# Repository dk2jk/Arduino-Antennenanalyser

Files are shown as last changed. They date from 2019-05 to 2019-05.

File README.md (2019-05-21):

<b>Arduino Antennenanalyser</b>

Dieser Antennenanalyser basiert auf Ver&ouml;ffendlichungen von K6BEZ und DG7EAO.

Der Antennenanalyser besteht aus einer Ohmschen SWR Messbr&uuml;cke('Resistive SWR Bridge'), die von einem DDS- Generator gespeist wird.

Die Einstellung der Frequenz und die Messung der Br&uuml;ckenspannung erfolgt &uuml;ber einen Arduino - Mikrocontroller.
Ein PC dient zur Anzeige und Bedienung.

<a href="https://github.com/dk2jk/arduino_antennenanalyser/tree/master/documents">->Beschreibung</a>

Bedienprogramm VNA.exe:
siehe: Abschnitt:&nbsp; "VNA PC Software"  in: <a href="http://www.dg7eao.de/arduino/antennen-analysator/">http://www.dg7eao.de/arduino/antennen-analysator/</a>

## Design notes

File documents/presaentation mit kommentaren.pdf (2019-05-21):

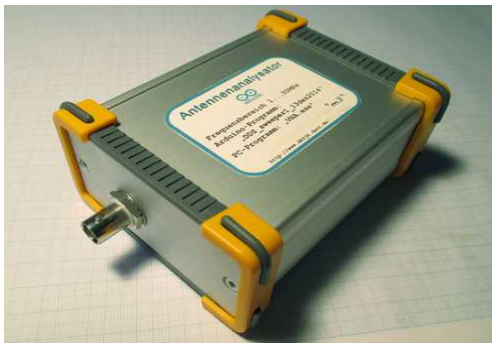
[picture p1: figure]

dk2jk | 1/13
DK2JK | 1/13

„Antennenanalyser“ mit ARDUINO

Titel

### „Antennenanalyser“ mit ARDUINO

Ein Selbstbauprojekt

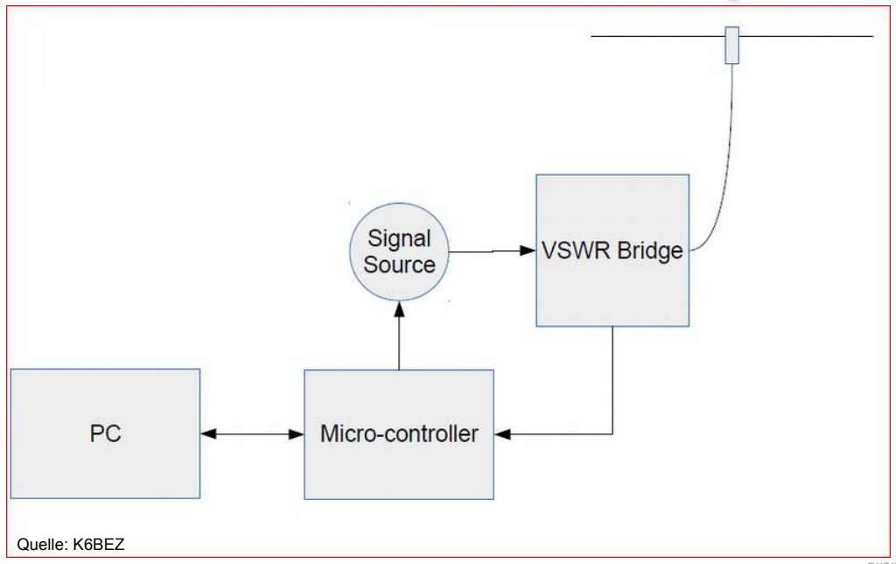
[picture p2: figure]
Quelle: K6BEZ

DK2JK 2/13

„Antennenanalyser“ mit ARDUINO

Block Diagramm

Das Blockdiagramm zeigt eine SWR-Messbrücke, die von einer Signalquelle gespeist wird. Ein Mikrocontroller steuert die Signalquelle und holt die Messwerte von der SWR-Messbrücke. Die Messwerte werden vom PC graphisch angezeigt

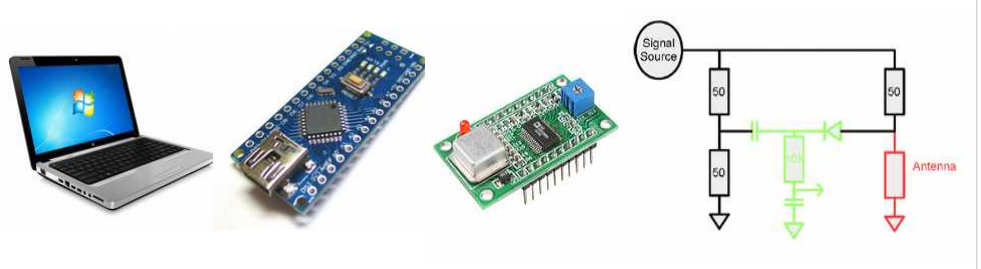
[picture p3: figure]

DK2JK 3/13

„Antennenanalyser“ mit ARDUINO

Komponenten

Windows PC | Arduino 'Nano' | DDS | Messbrücke
- CPU-Chip : Atmel Atmega328 16 MHz
- Modul fertig aufgebaut in SMD
- Bootlader via USB
- Entwicklungsoberfläche ( IDE) frei verfügbar
- Programmiersprache C / C++
- Preiswert ca. 4 Euro ( China )

●
- DDS-Chip : Analog Devices AD9850
- Modul fertig aufgebaut in SMD
- Schnittstelle : SPI ( Clock + Daten+ Update )
- Preiswert ca. 10Euro ( China)

●
- Messbrücke vgl. QRP-Report 1-2015

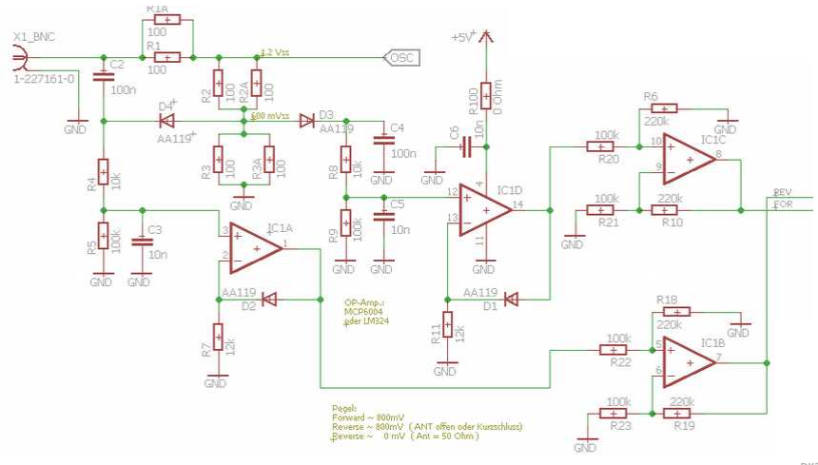
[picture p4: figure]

DK2JK 4/13

„Antennenanalyser“ mit ARDUINO

Schaltung Analogteil

Messbrücke : R1,R2,R3

V (forward) zwischen R2 und R3
V( reflected) zwischen R1 und BNC-Buchse
OP's hinter D3 / D4 sind log. Verstärker zum Kompensieren der Ge-Diodenkennlinie.
Der zweite OP hat die Verstärkung 2, so dass etwa max. 700mV am ADC anliegen. Der ADC misst von 0 bis 1,1 Volt ( Ref.Spannung).
Als OP muss ein Typ genommen werden, der bis Null Volt ohne neg. Betriebsspannung funktioniert ( LM324, 2x LM358) . Ein echter Rail-To-Rail-OP ist nicht erforderlich ( z.B. MCP 6004 ).

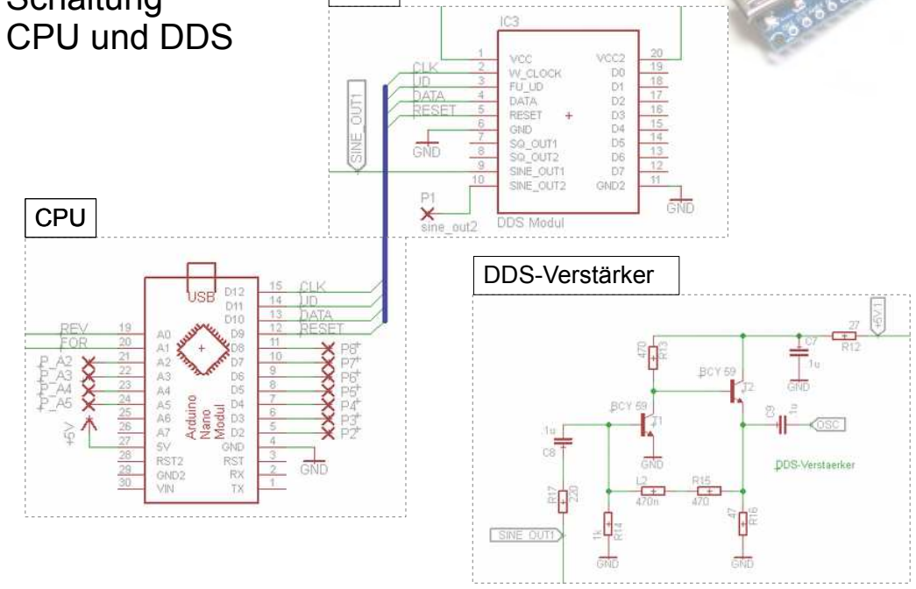
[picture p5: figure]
CPU und DDS; CPU; DDS-Verstärker

DK2JK 5/13

„Antennenanalyser“ mit ARDUINO

Schaltung

DDS

Zentrales Glied ist der DDS. Dieser ist einstellbar von 1 Hz bis 30 Mhz. Je höher die Frequenz ist, desto 'treppenförmiger' sieht die Ausgangsspannung aus ( Oszillator = 125 MhHz ).
Die Programmierung des DDS erfolgt sehr einfach über eine serielle Schnittstelle mit den Signalen Clock, Date und Chipselect ( SPI).
Der DDS liefert ca. 400mV ss, was für die Messbrücke etwas wenig ist. Deshalb wird hier ein Verstärker nachgeschaltet, der das Signal auf 1,4 Vss anhebt. Andere Schaltungsbeispiele verwenden hier einen MMIC, dem jedoch ein Dämpfungsglied vorgeschaltet werden muss.

DK2JK 6/13

„Antennenanalyser“ mit ARDUINO

Layout

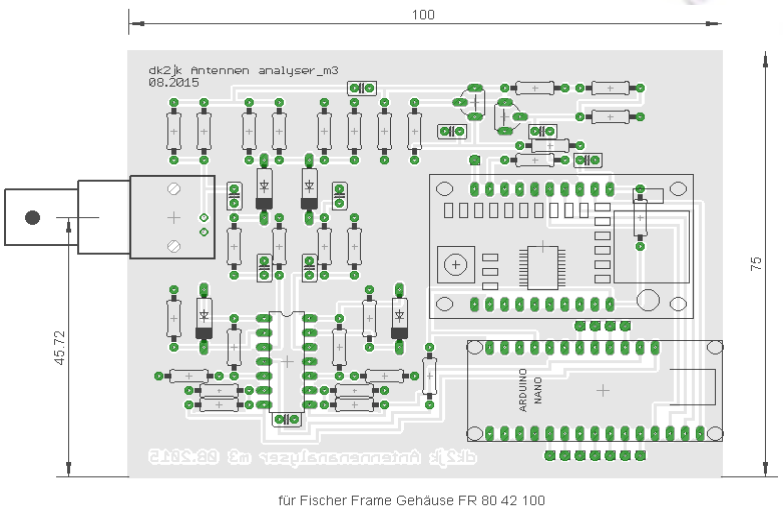
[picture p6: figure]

Hier ein Layout 100 mm x 75 mm

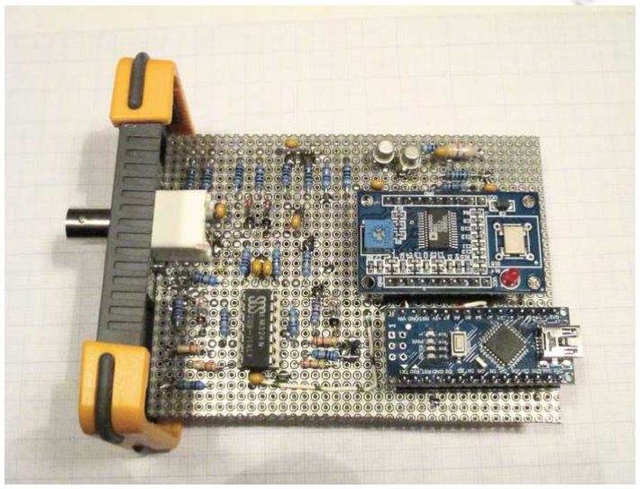
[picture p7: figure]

DK2JK 7/13

„Antennenanalyser“ mit ARDUINO

Prototyp

Die Platine wurde in ein Fischer 'Frame Gehäuse' eingebaut; ebenso würde ein Profilgehäuse TUF 80 42 100 ME gehen ( ohne die
Kunststoffrahmen ) .
Die einzig notwendigen mechanischen Arbeiten sind ist das Sägen des Lochs für die BNC-Buchse und die USB-Buchse.
Die Platine passt in eine der vorhandenen Führungen im Gehäuse.

Der Arduino sitzt knapp am Rand, damit auch USB-Stecker mit etwas dickerem Stecker passen.
Zwischen Front und BNC-Buchse müssen noch 2mm untergelegt werden, da durch die Gummidichtungen die Front nicht direkt am Rahmen liegt. (Die Platine wurde für 100mm Gehäusetiefe entworfen ).
( Masseverbindung zwischen Platine und Gehäuse ist zu prüfen)

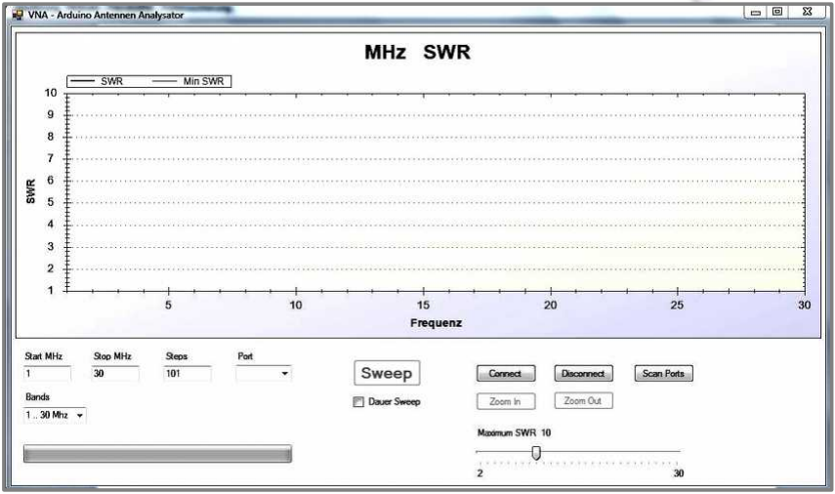
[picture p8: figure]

DK2JK 8/13

„Antennenanalyser“ mit ARDUINO
PC-Programm „VNA.exe“

Quelle: DG7EAO

Hier die Bedienoberfläche von Norbert DG7EA0 ( in Visual Basic geschrieben).
Gestartet wird mit 'Scan Ports'. Im Listenfeld 'Ports' wählt man den benutzten Port aus; evtl. im Gerätemanager nachschauen. Mit 'Connect' und 'Sweep' startet der Scanvorgang.
Der Frequenzbereich ( Start, Stop ) kann geändert werden, ebenso die Auflösung ( 'Steps' ).

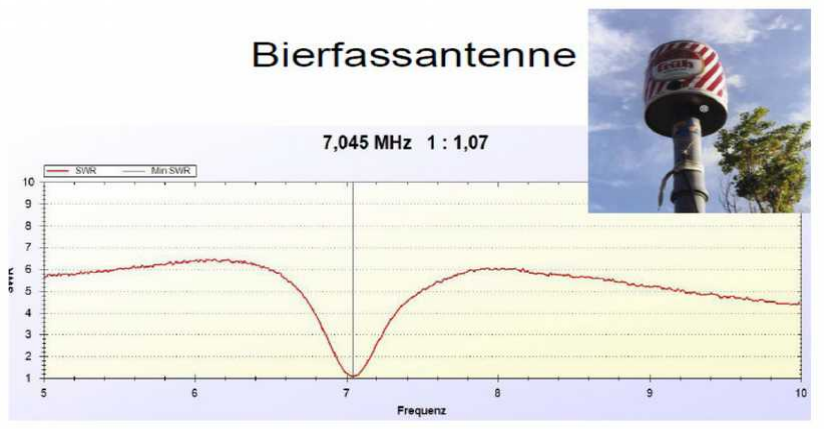
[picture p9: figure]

DK2JK 9/13

„Antennenanalyser“ mit ARDUINO

Messung(1)

Hier als Beispiel die Messung einer Bierfassantenne.

Was kann man noch alles damit anstellen ?

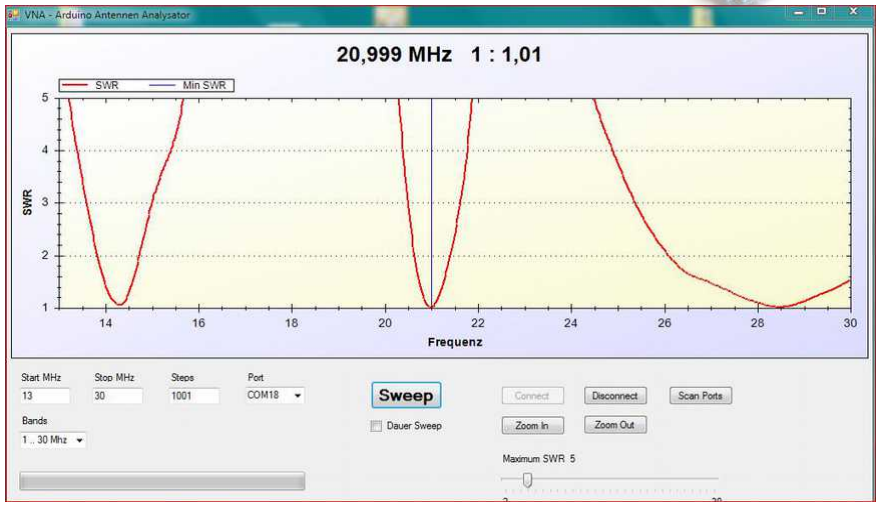
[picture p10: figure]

DK2JK 10/13

„Antennenanalyser“ mit ARDUINO

Messung(2)

Fritzel GPA

Hier als Beispiel die Messung einer 3 Band Fritzel GPA

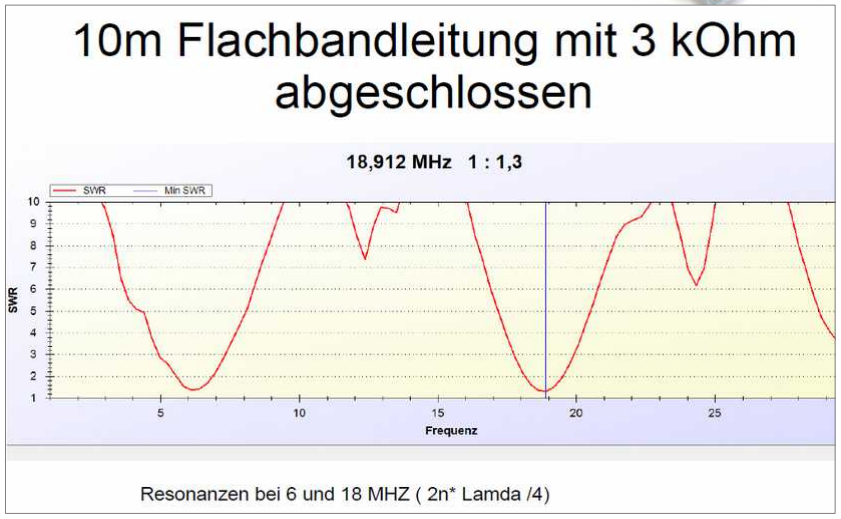
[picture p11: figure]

DK2JK 11/13

„Antennenanalyser“ mit ARDUINO

Messung(3)

Hier als Beispiel die Messung einer Flachbandleitung ( alte Fernsehleitung ).

Verkürzungsfaktor 6/7 ~ 0,85
Zur Erinnerung : Lambda/ 4 transformiert Hochohmig in Niederohmig.

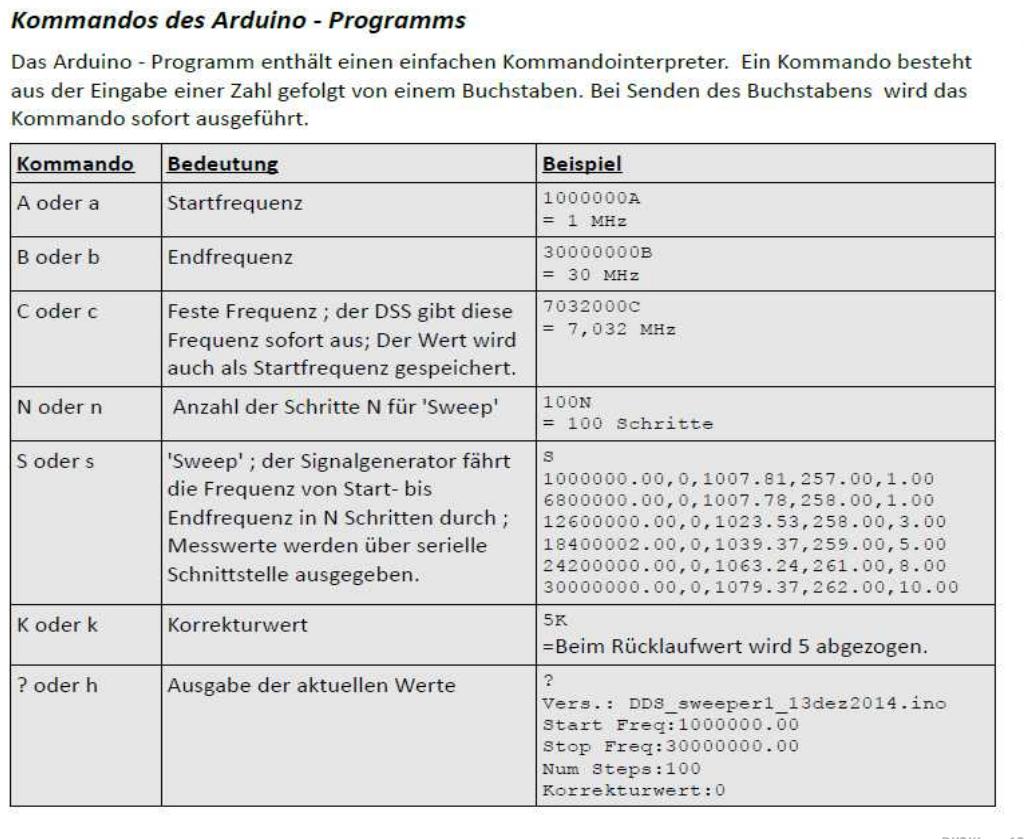
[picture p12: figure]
„Antennenanalyser“ mit ARDUINO

DK2JK 12/13

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
Die Bedienung des Arduino erfolgt über einfache Kommandos.
Mit dem Kommnado 's' wird die Messreihe in Form einer Tabelle ausgegeben, die mit dem PC-Programm VNA.exe graphisch angezeigt wird. Es würde auch mit EXCEL gehen.

DK2JK 13/13

„Antennenanalyser“ mit ARDUINO

Quellen

K6BEZ:
http://www.hamstack.com/hs_projects/antenna_analyzer_docs.pdf

DG7EAO :
http://lima05web.wordpress.com/2014/03/22/arduino-antennen-analysator-dg7eao/

DK2JK:
http://dk2jk.darc.de/arduino/antennenanalyser/

DDS:
http://www.analog.com/static/imported-files/data_sheets/AD9850.pdf

Arduino:
http://www.arduino.cc/

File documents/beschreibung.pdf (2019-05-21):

# Antennenanalyser mit Arduino

# Beschreibung

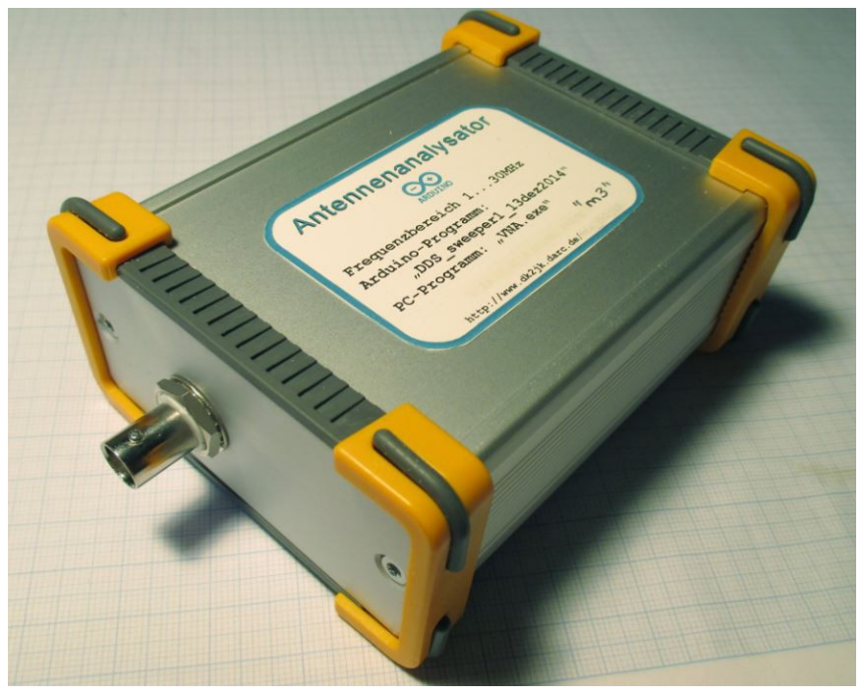
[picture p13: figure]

Seite 1 von 11 Seiten (03.2016 dk2jk)

### 1. Allgemein

Der Antennenanalyser besteht aus einer Ohmschen SWR Messbrücke( 'Resistive SWR Bridge'), die von einem DDS- Generator gespeist wird. Die Einstellung der Frequenz und die Messung der Brückenspannung erfolgt über einen Arduino -Mikrocontroller. Ein PC dient zur Anzeige und Bedienung.

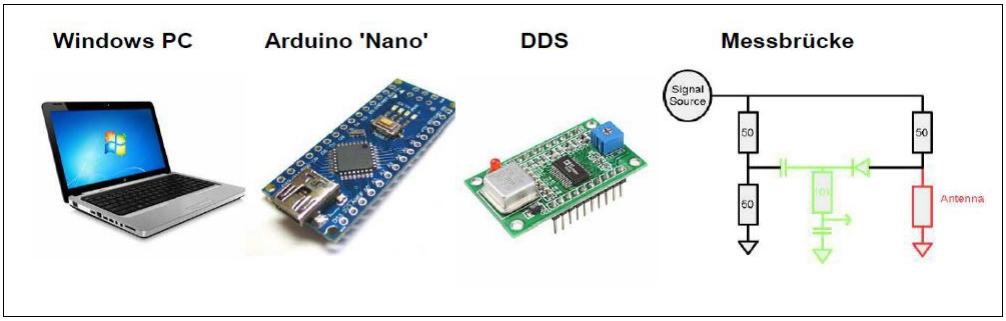
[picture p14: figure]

### 2. Anwendungen

- SWR- Messung 1 bis 30 Mhz
- Signalgenerator bis 30Mhz
- Resonanzmessung
- Telegraphie - Bakensender

### 3. Schaltungsbeschreibung

Die Frequenz des DDS AD9850 wird über 4 Steuerleitungen vom Mikrocontroller eingestellt. Die Frequenz kann auf 1 Hz genau programmiert werden. Das Ausgangssignal ist nahezu sinusförmig. Der DDS liefert einen Pegel von ca. 400mVss. Dieses Signal wird durch den DDS- Verstärker mit den Transistoren Q1 & Q2 verstärkt und auf ca. 1Vss an 50 Ohm angehoben.
Die Messung der Brückenspannung erfolgt über zwei Messkanäle. Jeder Messkanal besteht aus einer Spitzenwertgleichrichtung mit nachfolgendem logarithmischen Verstärker, welcher mit der gleichen Dioden bestückt ist wie der Gleichrichter; so wird die nichtlineare Kennlinie des Spitzenwertgleichrichters kompensiert. Es werden Germaniumdioden ( AA1xx, OAxx, 1N34, 1N60P ) verwendet, da Siliziumdioden bei dem geringen Pegel noch keine ordentliche Spannung liefern. Im Prototyp werden 1N60P verwendet. Der zweite OP verstärkt das Signal auf ca. 500mV am Eingang des Analog-Digital-Wandlers des Mikrocontrollers. Um bei den kleinen Spannungen im mV - Bereich die Offsetfehler klein zu halten, sind die OPs möglichst symmetrisch beschaltet. Als OP genügt ein LM324, der bei + 5Volt und 0-Volt- Versorgung Ausgangsspannungen von 0 Volt bis ca. 3 Volt Ausgangsspannung liefert.

Seite 2 von 11 Seiten (03.2016 dk2jk)

Abb. 1: Komponenten [Ref.1]

### 4. Aufbau

Alle Bauelemente befinden sich auf einer Platine 100mm x 75mm, die in die Führungsschienen eines Profilgehäuses passt ( Fischer Frame Gehäuse FR 80 42 100 ME [Ref.6] ). Das DDS- und Arduino - Nano- Modul sind in IC- Sockel mit doppeltem Federkontakt gesteckt. Für die Bestückung von Hand hat die Platine extra große Pads mit Durchkontaktierungen. Die Platine wird durch die BNC-Buchse an der Front festgehalten.

### 5. Bestückung

- Arduino- Board vorbereiten: Das Arduino- Modul hat je nach Lieferung evtl. noch keine Stiftleisten; Dazu werden ein passender IC- Sockel, die mitgelieferten 15-poligen Stifte und die Nano-Board-Platine zusammengesteckt und die Stifte oben an 4 Ecken verlötet. Die Stifte werden senkrecht ausgerichtet und endgültig verlötet. Die 6-pol. Stiftleiste auf dem Nano-Board ( ISP-Stecker) braucht nicht bestückt werden.
- IC-Sockel für Nano-Board vorbereiten: Aus einem 40-
poligen IC-Sockel wird ein 2 x 15-poliger
geschnitten; bei älteren Platinen gibt es an der 'Nord-Ost-Seite' für 3 Pins des Nano-Boards keine Pads, daher müssen die zugehörigen Stifte des Sockels flachgelegt werden. Zunächst IC-Sockel an 4 äußeren Pins fixieren und dann endgültig anlöten.
- IC-Sockel für das DDS-Board vorbereiten: Ein 20-poliger IC-Sockel wird in der Mitte zu 2 x 10 Pins längs geteilt. Nun das DDS-Board auf die Kontaktreihen stecken und auf der Platine platzieren. Den IC-Sockel an 4 äußeren Pins fixieren und dann endgültig anlöten.
- Entfernen des DDS - Moduls und des Nano-Boards.
- Bestückung der restlichen Bauelemente, wobei mit den
niedrigsten begonnen wird. Falls die Bauelemente nicht
sortiert sind, erst messen und sofort an passender Stelle einlöten. Bei den Dioden Polarität beachten!
- Einlöten der BNC - Buchse; hierbei darauf achten, dass diese rechtwinklig auf der Platine sitzt.
- Zuletzt den OP in den 14-poligen IC_Sockel stecken.
- DDS - Modul und Nano-Board wieder stecken.

### 6. Verbindung Aufnehmen

Was wird benötigt?
- USB-Kabel mit USB Mini-Stecker.
- | Arduino Programm | 'dds_sweeper_xx.ino' | [Ref.3]
- Programm 'VNA.EXE' mit zugehörigen DLLs [Ref.2]
- Microsoft Runtime Library DotNet 4.x
- Arduino IDE z.B. Arduino 1.6.x [Ref.5]

Die Module „DDS“ und „Arduino Nano“ sind
gesteckt. Nun wird der USB-Port mit dem Rechner verbunden. Jetzt sollte am Nano-Board die grüne und am DDS- Board die rote Power-LED leuchten. Falls der PC das Board nicht erkennt, so ist die Installation eines Treibers erforderlich [Ref. 3].
Nun wird die Arduino - IDE aufgerufen. Als erstes wird das Board 'Nano' ausgewählt und der COM -Port eingestellt.

Seite 3 von 11 Seiten (03.2016 dk2jk)

Abb. 2: Arduino-Nano-Sockel

Abb. 3: DDS-Sockel

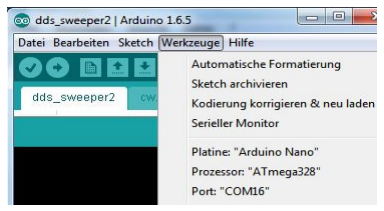
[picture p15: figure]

Abb. 4 COM-Port

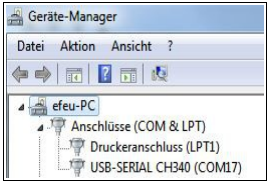
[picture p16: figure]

Zum Überprüfen, welcher COM- Port vom Arduino belegt wird, kann man im Gerätemanager nachsehen („devmgmt.msc“); dort nach „USB -Serial CH340“ suchen.

### 7. Erster Test

Arduino mit Programm 'dds_sweeper2.ino' [Ref.3] laden. Mit dem Knopf 'Hochladen' ( Pfeil nach rechts ) oder 'Strg+U' wird ein Programm in den Arduino -Mikrocontroller geladen. Nach dem Hochladen rufen wir den seriellen Monitor des Arduino auf über 'Werkzeuge' -> 'serieller Monitor'. Die Baudrate muss auf 57600 stehen! Nun geben wir in der Eingabezeile des Monitors ein
'7032000c' ( d.h. 7,032 Mhz als Dauersignal )
Das Programm sendet nun ein Dauersignal auf 7,032 Mhz. Auf dieser Frequenz 7,032 Mhz sollte jetzt ein Träger hörbar sein. Evtl. die Frequenz nach eigenen Bedürfnissen einstellen.

### 8. Offset prüfen

Zum Prüfen des Offsets geben wir die Frequenz Null ein
'0a0b10n' ( d.h. Von 0 Mhz bis 0 Mhz in 10 Schritten )
Mit
's'
wird der Durchlauf ( Sweep ) gestartet. Die Anzeigewerte für Vorlauf und Rücklauf in der 4. und 5. Spalte sollten nahe Null sein ( < 40 ). Ohne Eingangssignal wird nur der Offset gemessen;

### 9. Funktionstest 'dds-sweeper'

Wir nehmen eine KW-Empfänger und stellen ihn auf eine Frequenz ein ( Beispiel: 7,032 Mhz ). Als Betriebsart wählen wir CW oder SSB. Jetzt tippen wir am Terminal ( „Arduino – Serial - Monitor“ ) ein:
'7032000c' | ( d.h. 7,032 Mhz als Dauersignal )
'?' | | ( d.h. Statusanzeige )
Die Eingabe erfolgt in „Hertz“ . Das Kommando 'c' stellt diese Frequenz ein und das Kommando '?' zeigt die aktuellen Einstellungen auf dem Bildschirm an. Im KW-Empfänger sollte jetzt ein Signalton hörbar sein; vielleicht kann man einen kurzen Draht als Antenne in die Koaxbuchse als „Sendeantenne“ stecken. Wir können auch den Bereich, der durchlaufen wird, ausprobieren: ( Die Eingaben werden immer mit der Enter - Taste abgeschlossen ). Wir tippen ein:
'7000000a' | Startfrequenz = 7.000 MHz
'7001000b' | Endfrequenz = 7.001 MHz
| '?' | Status Anzeige
Jetzt | 's' | eingeben: Das Terminal zeigt die durchlaufenen Frequenzen an.

Im KW-Empfänger müsste jetzt ein ansteigender oder abfallender Ton hörbar sein – je nach eingestelltem Seitenband.

Noch ein Experiment: Wir ändern die Schrittanzahl ( 'Num Steps' ) auf 10, indem wir eingeben:
'10n' | ( d.h. 10 Schritte )
Wenn wir jetzt wieder 's' eingeben, sollte man im KW-Empfänger deutlich die Frequenzschritte hören können. Wir haben bis jetzt nachwiesen, dass der DDS Signale erzeugt.

Seite 4 von 11 Seiten (03.2016 dk2jk)

Abb. 5: Gerätemanager

Jetzt schließen wir wieder den 50-Ohm-Widerstand an. Eine Ausgabe von Daten erfolgt mit dem Kommando 's' am Terminal ( „Arduino – Serial -Monitor“ ) :
Die 3. Spalte gibt den SWR - Wert mal 1000 wieder; es sollten also bei einem 50-Ohm
Abschlusswiderstand Werte etwas größer als 1000 entsprechend einem SWR von 1.0 angezeigt werden.

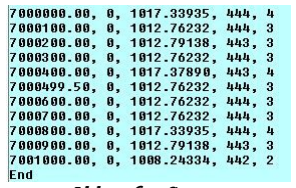
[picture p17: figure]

Die Tests jetzt mit den anderen Widerständen wiederholen:
100 Ohm | SWR= 2,0 | 25 Ohm | SWR= 2,0
75 Ohm | SWR= 1,5 | 33,3 Ohm | SWR= 1,5
150 Ohm | SWR= 3,0
Die Werte sollten ungefähr eingehalten werden. An dieser Stelle muss betont werden, dass dieser 'Antennenanalyser' kein Präzisionsinstrument ist.

### 10. Bedienoberfläche VNA.exe

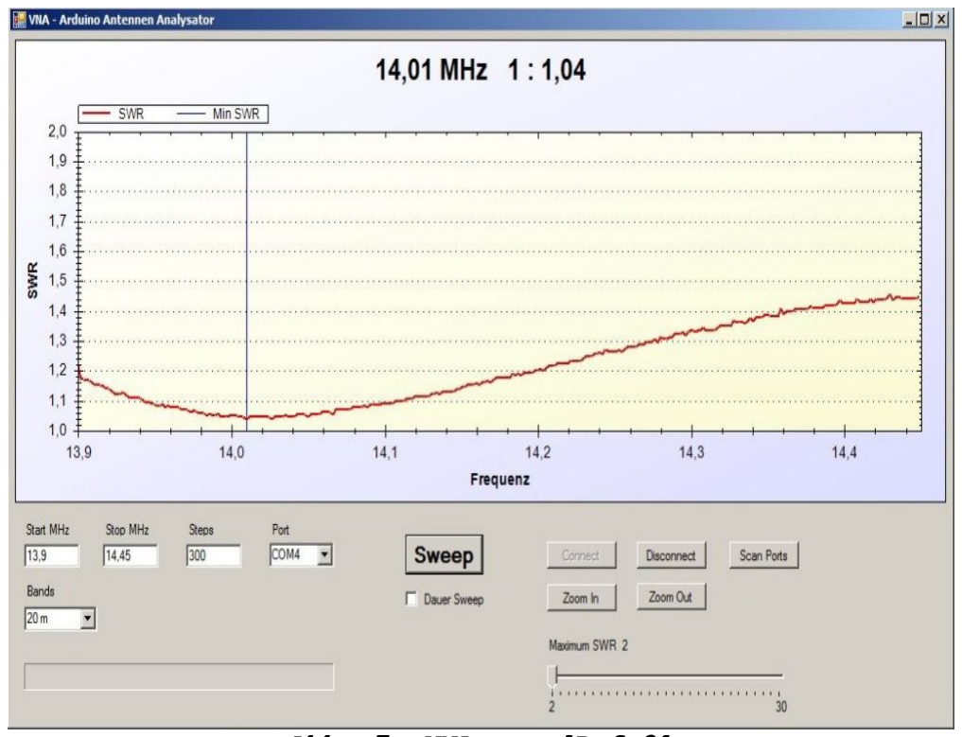
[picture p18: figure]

Die Software ist unter DotNet programmiert und benötigt eine aktuelle Version des DotNet Frameworks (Version 4.0 oder höher). Dieses kann kostenlos von Microsoft herunter geladen werden. Ein Software Installation ist nicht erforderlich. Es reicht, das Verzeichnis mit den Programmdateien an eine beliebige Stelle zu kopieren und die Datei VNA.exe zu starten. Nach dem Programmstart wählt man unter Port die Com - Schnittstelle des USB – Adapters aus. Mit einem Klick auf Connect wird eine serielle Verbindung zum Arduino Modul hergestellt. Unter Start MHz und Stop MHz ist der Frequenzbereich 1 .. 30 MHz voreingestellt. Diesen kann man beliebig ändern oder mit der Auswahlbox Bands ein Amateurfunkband wählen. Durch einen Klick auf Sweep werden die Daten an das Arduino Modul gesendet, dieses antwortet mit den entsprechenden SWR - Werten. Aus diesen wird dann eine Verlaufskurve gezeichnet. Unter Steps ist als Wert 101 eingestellt. Dies bedeutet, dass bei einem Frequenz - Sweep 101 Frequenzen gemessen werden. Man kann diesen Wert bis auf 1000 erhöhen, dann bekommt man eine höhere Auflösung mit bis zu 1000 Messpunkten – die Messung dauert dann aber etwas länger. Die Auflösung erhöht sich auch, wenn man den Frequenzbereich verkleinert, z.B. statt 1 .. 30 MHz >> 13 .. 15 MHz. Dies erreicht man auch

Seite 5 von 11 Seiten (03.2016 dk2jk)

Abb. 6: Sweep

Abb. 7: VNA.exe [Ref.2]

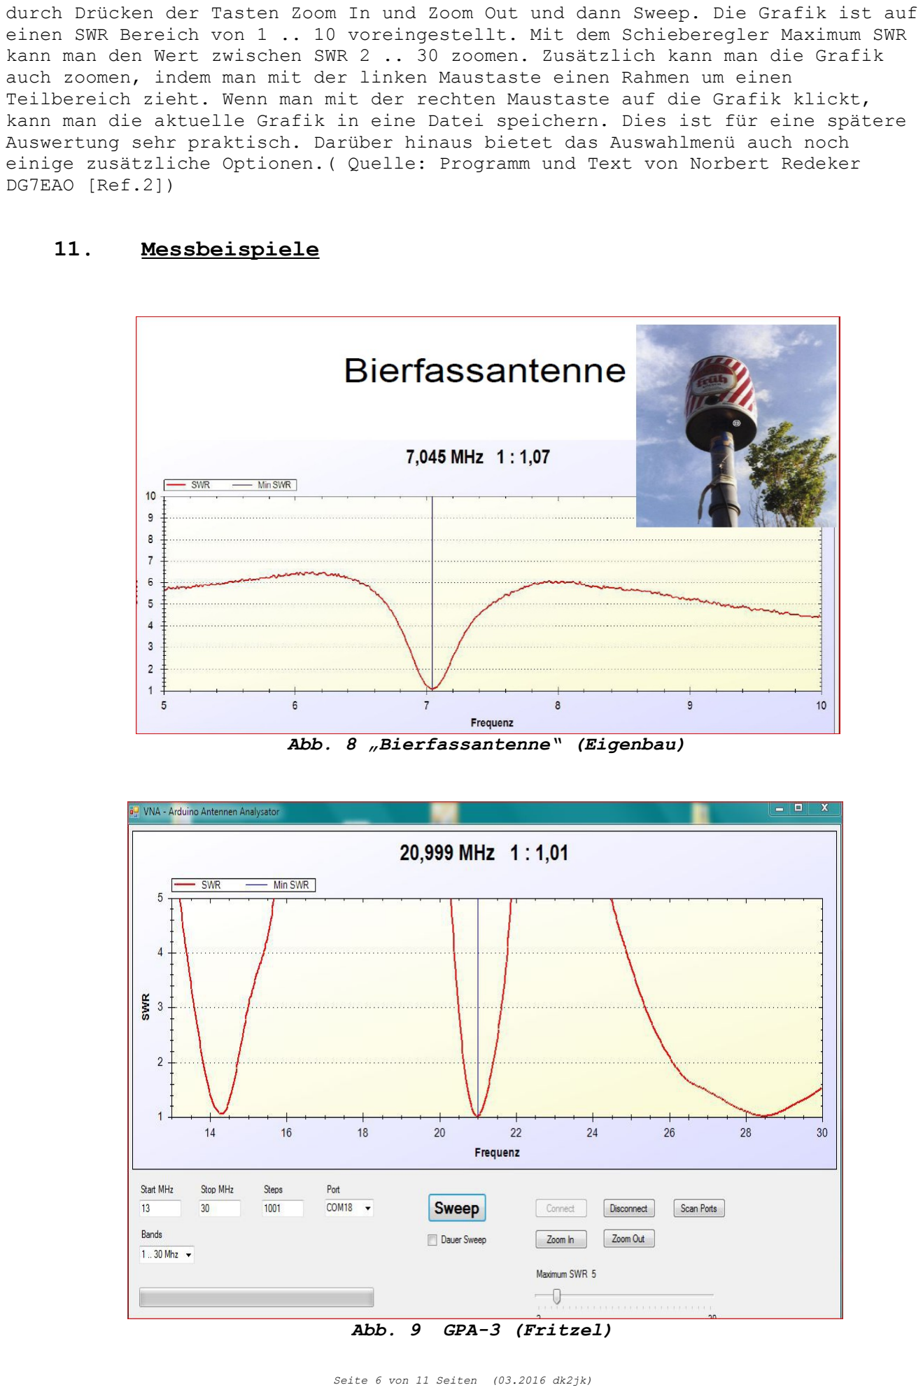
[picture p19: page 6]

durch Drücken der Tasten Zoom In und Zoom Out und dann Sweep. Die Grafik ist auf einen SWR Bereich von 1 .. 10 voreingestellt. Mit dem Schieberegler Maximum SWR kann man den Wert zwischen SWR 2 .. 30 zoomen. Zusätzlich kann man die Grafik auch zoomen, indem man mit der linken Maustaste einen Rahmen um einen Teilbereich zieht. Wenn man mit der rechten Maustaste auf die Grafik klickt, kann man die aktuelle Grafik in eine Datei speichern. Dies ist für eine spätere Auswertung sehr praktisch. Darüber hinaus bietet das Auswahlmenü auch noch einige zusätzliche Optionen.( Quelle: Programm und Text von Norbert Redeker DG7EAO [Ref.2])

### 11. Messbeispiele

Seite 6 von 11 Seiten (03.2016 dk2jk)

Abb. 8 „Bierfassantenne“ (Eigenbau)

Abb. 9 GPA-3 (Fritzel)

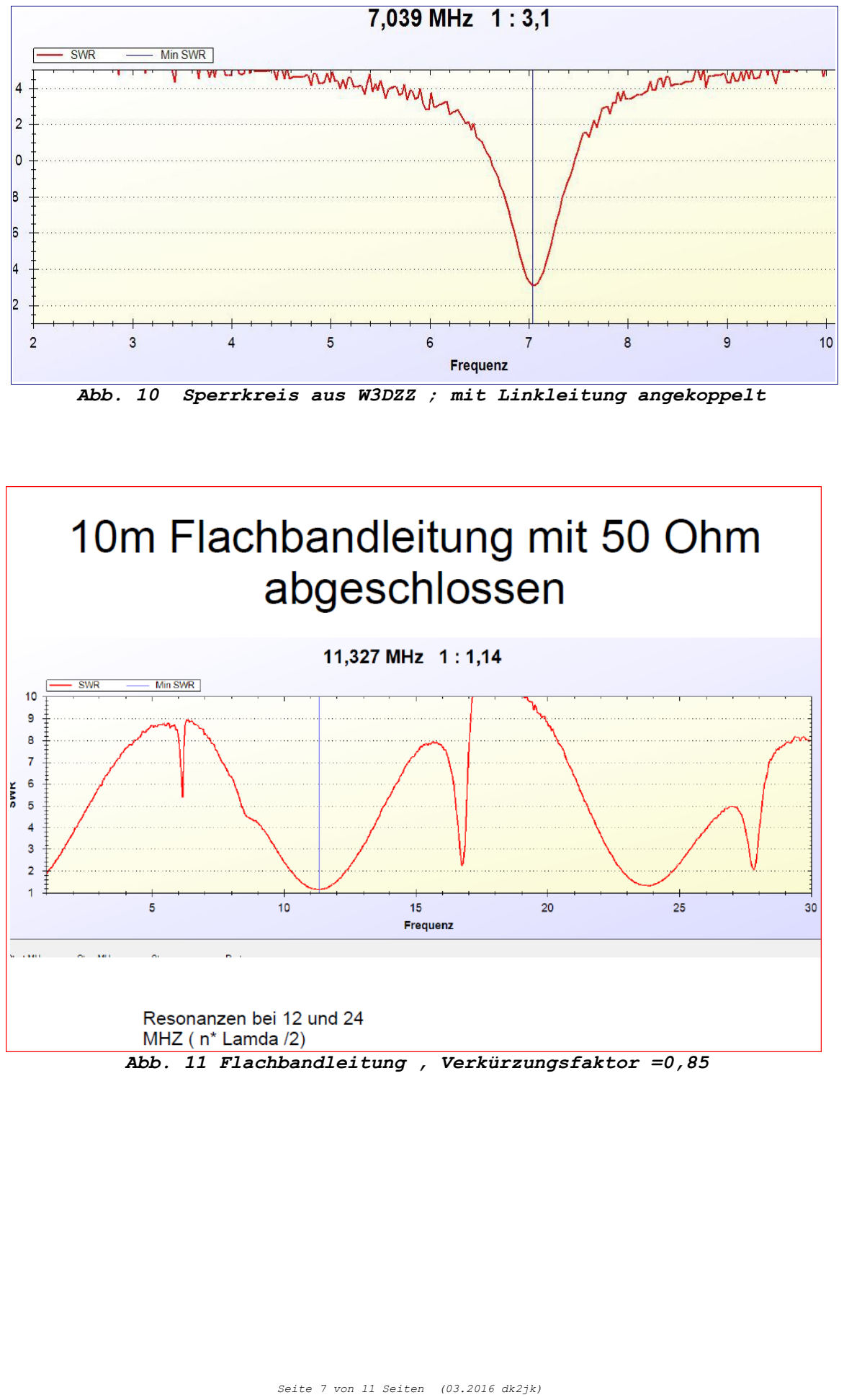
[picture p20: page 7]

Seite 7 von 11 Seiten (03.2016 dk2jk)

Abb. 10 Sperrkreis aus W3DZZ ; mit Linkleitung angekoppelt

Abb. 11 Flachbandleitung , Verkürzungsfaktor =0,85

### 12. Gimmicks

Als Spielerei wurde noch
ein Bakensender
implementiert. Ein im
EEPROM gespeicherter Text
wird auf der Startfrequenz wiederholt als
Morsezeichen gesendet. Der
Text wird mit
Ausrufezeichen beginnend

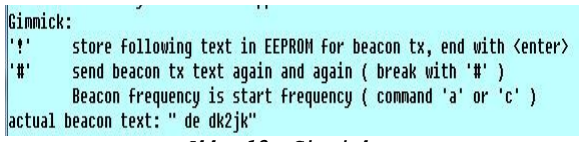
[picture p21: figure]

und mir Enter endend eingegeben. Der Text ist nun im EEPROM gespeichert. Mit dem Kommando '#' wird dieser Text gesendet. Die Sendefrequenz wird z.B. mit 7032000c eingegeben ( 7,032 Mhz ). Zum Beenden der Bakensendung muss wieder '#' eingegeben werden.

### 13. Befehlsliste

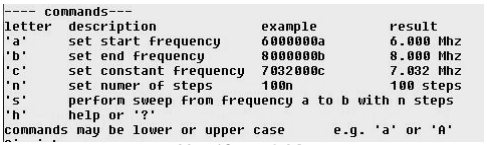
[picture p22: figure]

### 14. Quellen

[Ref.1] K6BEZ:
http://www.hamstack.com/hs_projects/antenna_analyzer_docs.pdf
[Ref.2] DG7EAO :
http://lima05web.wordpress.com/2014/03/22/arduino-antennen-analysator-dg7eao/[Ref.3] DK2JK:
http://dk2jk.darc.de/arduino/index_arduino.html ( → Prototyp 'm4' ) http://dk2jk.darc.de/arduino/antennenanalyser/CH341SER.ZIP (Treiber für CH340) [Ref.4] DDS:
http://www.analog.com/static/imported-files/data_sheets/AD9850.pdf
[Ref.5] Arduino:
http://www.arduino.cc/ (http://www.arduino.cc/%20)
[Ref.6] Gehäuse:
http://www.fischerelektronik.de/http://www.schubert-gehaeuse.de/ (http://www.fischerelektronik.de/)

Seite 8 von 11 Seiten (03.2016 dk2jk)

Abb. 12: Gimmicks

Abb. 13: Befehle

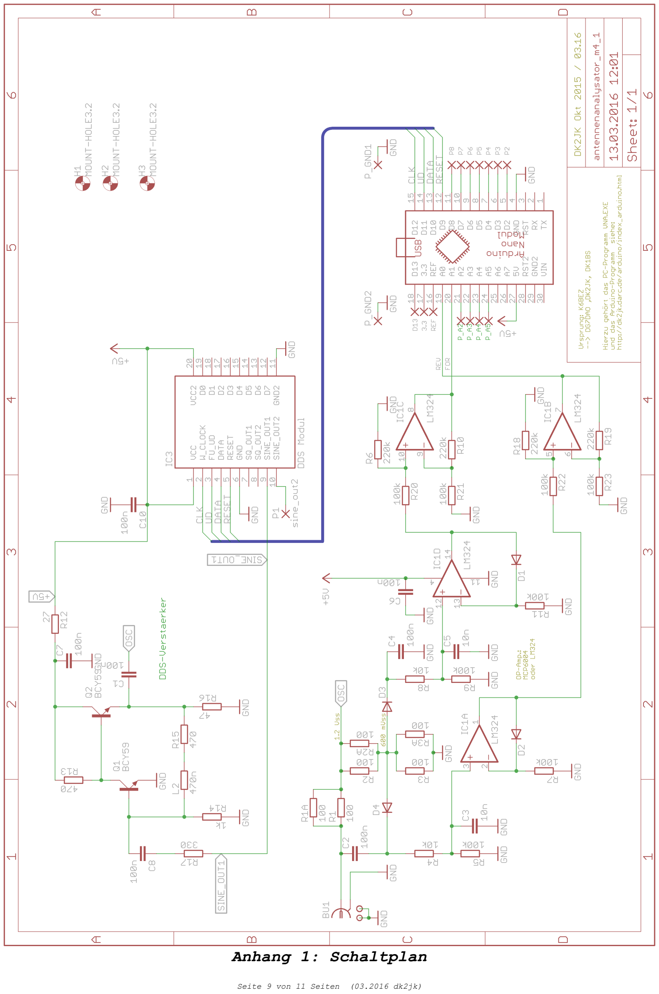
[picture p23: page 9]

Seite 9 von 11 Seiten (03.2016 dk2jk)

Anhang 1: Schaltplan

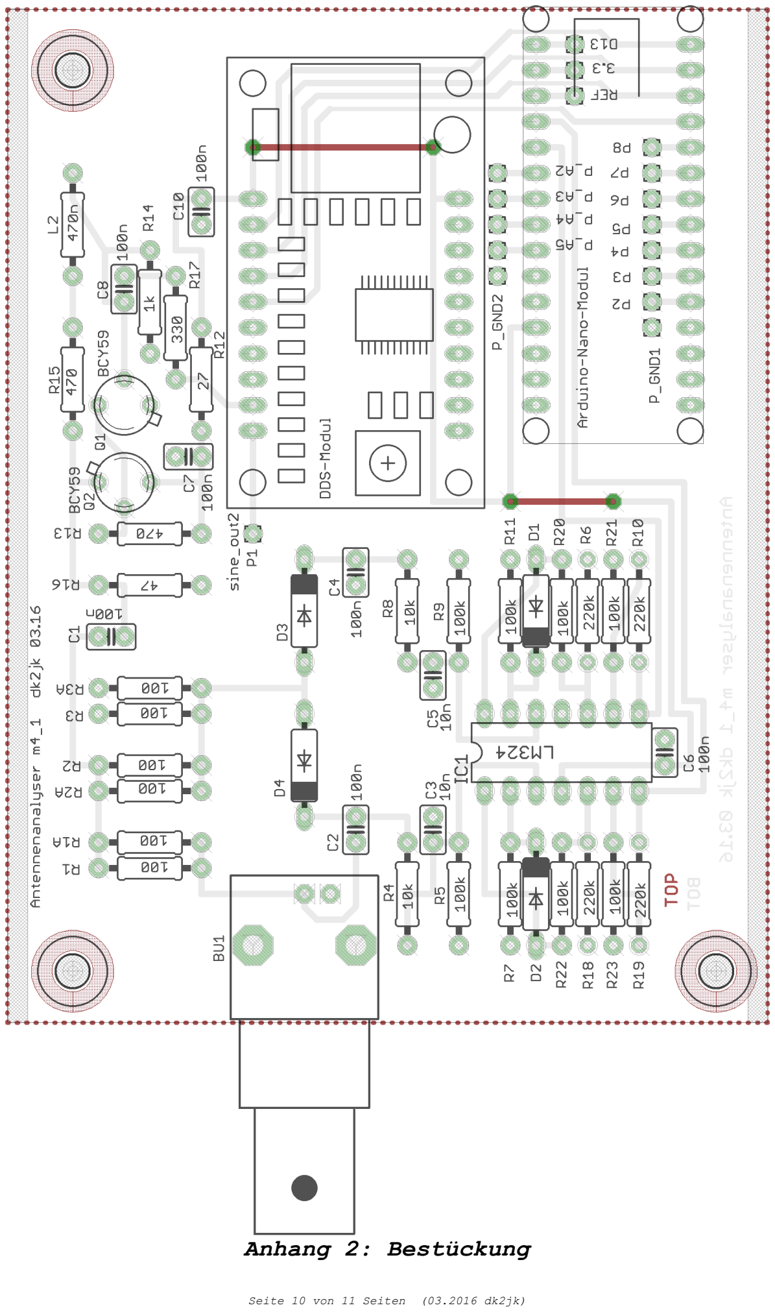
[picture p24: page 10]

Seite 10 von 11 Seiten (03.2016 dk2jk)

Anhang 2: Bestückung

Seite 11 von 11 Seiten (03.2016 dk2jk)

Anhang 3: Stückliste

Position | Anzahl | Bauteil | Wert | Beschreibung
1 | 1 | BU1 | BNC | UG 1094W1
2 | 7 | C1 | 100n | X7R-2,5 xx
| | C2 | 100n | X7R-2,5 xx
| | C4 | 100n | X7R-2,5 xx
| | C6 | 100n | X7R-2,5 xx
| | C7 | 100n | X7R-2,5 xx
| | C8 | 100n | X7R-2,5 xx
| | C10 | 100n | X7R-2,5 xx
3 | 2 | C3 | 10n | X7R-2,5 xx
| | C5 | 10n | X7R-2,5 xx
4 | 4 | D1 | Ge- Diode | 1N34, 1N60P , AA119, , OAxx
| | D2 | Ge- Diode | 1N34, 1N60P , AA119, , OAxx
| | D3 | Ge- Diode | 1N34, 1N60P , AA119, , OAxx
| | D4 | Ge- Diode | 1N34, 1N60P , AA119, , OAxx
5 | 1 | IC1 | LM324 | OP AMP evtl. MCP 6004
6 | 1 | L2 | 470nH | SMCC 0,47uH evtl. Luftspule 7mm=L, 4mm=D, 16=N
7 | 2 | Q1 | BCY59 | NPN TRANSISTOR Universal BC337, BCY59 o.ä.
| | Q2 | BCY59 | NPN TRANSISTOR Universal BC337, BCY59 o.ä.
8 | 6 | R1 | 100 | Widerstand Metallschicht 0207 1%
| | R1A | 100 | Widerstand Metallschicht 0207 1%
| | R2 | 100 | Widerstand Metallschicht 0207 1%
| | R2A | 100 | Widerstand Metallschicht 0207 1%
| | R3 | 100 | Widerstand Metallschicht 0207 1%
| | R3A | 100 | Widerstand Metallschicht 0207 1%
9 | 8 | R5 | 100k | Widerstand Metallschicht 0207 1%
| | R7 | 100k | Widerstand Metallschicht 0207 1%
| | R9 | 100k | Widerstand Metallschicht 0207 1%
| | R11 | 100k | Widerstand Metallschicht 0207 1%
| | R20 | 100k | Widerstand Metallschicht 0207 1%
| | R21 | 100k | Widerstand Metallschicht 0207 1%
| | R22 | 100k | Widerstand Metallschicht 0207 1%
| | R23 | 100k | Widerstand Metallschicht 0207 1%
10 | 2 | R4 | 10k | Widerstand Metallschicht 0207 1%
| | R8 | 10k | Widerstand Metallschicht 0207 1%
11 | 1 | R14 | 1k | Widerstand Metallschicht 0207 1%
12 | 4 | R6 | 220k | Widerstand Metallschicht 0207 1%
| | R10 | 220k | Widerstand Metallschicht 0207 1%
| | R18 | 220k | Widerstand Metallschicht 0207 1%
| | R19 | 220k | Widerstand Metallschicht 0207 1%
13 | 1 | R12 | 27 | Widerstand Metallschicht 0207 1%
14 | 1 | R17 | 330 | Widerstand Metallschicht 0207 1%
15 | 1 | R16 | 47 | Widerstand Metallschicht 0207 1%
16 | 2 | R13 | 470 | Widerstand Metallschicht 0207 1%
| | R15 | 470 | Widerstand Metallschicht 0207 1%
17 | 1 | Gehäuse | 80x100 | FISCHER Frame-Gehäuse FR 80 42 100 ME
18 | 1 | Platine | 100 x 75 | W09973AS1 / 3PCB
19 | 1 | IC-Sockel | 40-polig | IC-Sockel, 40-polig, doppelter Federkontakt , auf 2x 15 gekürzt
29 | 1 | IC-Sockel | 20-polig | IC-Sockel, 20-polig, doppelter Federkontakt ,in 2x 10 geteilt
30 | 1 | IC-Sockel | 14-polig | IC-Sockel, 14-polig, doppelter Federkontakt ,
31 | 1 | ARDIUNO | ARDUINO | Arduino Nano Modul
32 | 1 | DDS | DDS | AD9850 DDS Module / China

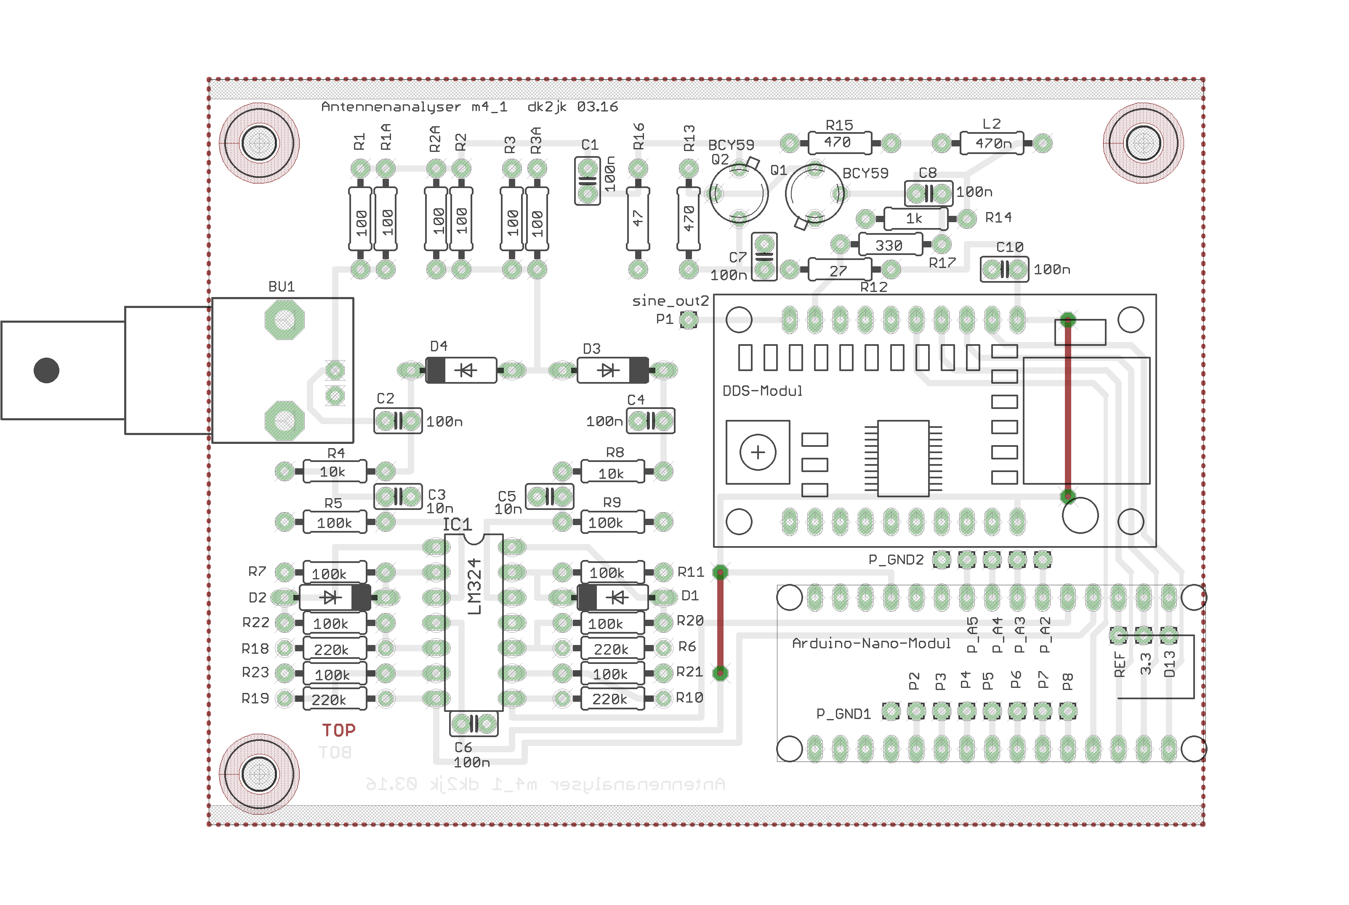
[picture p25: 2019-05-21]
documents/bestückung.png

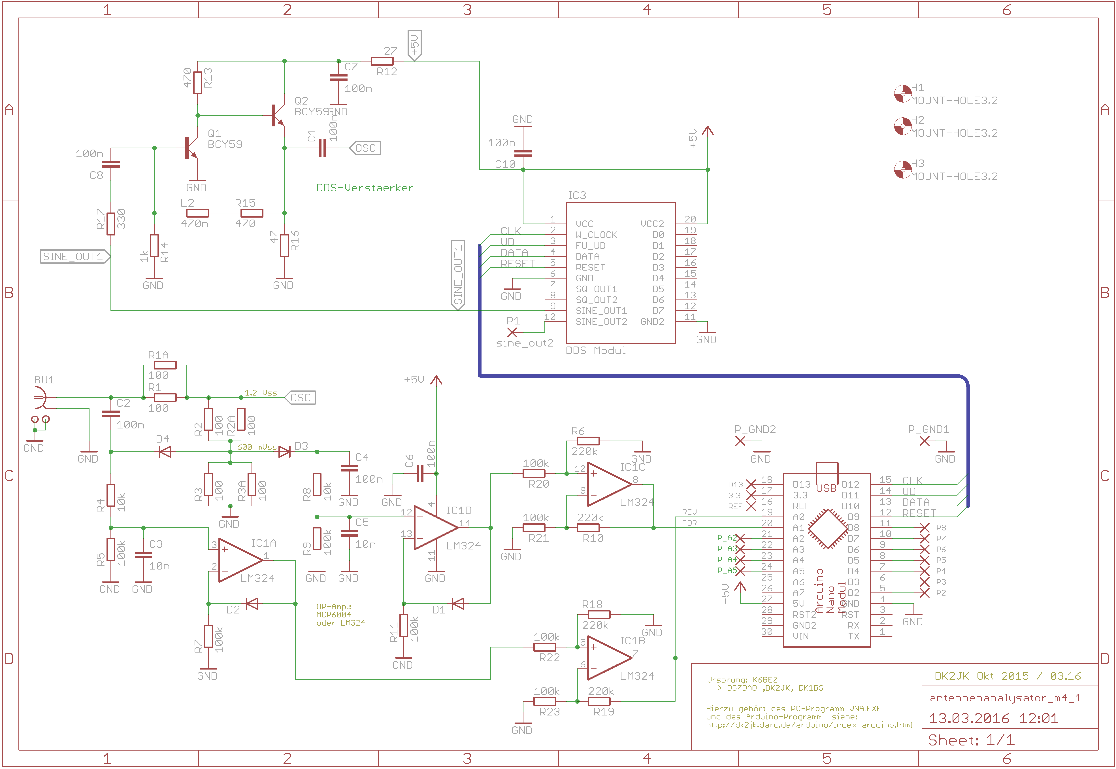
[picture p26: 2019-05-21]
documents/schaltbild.png

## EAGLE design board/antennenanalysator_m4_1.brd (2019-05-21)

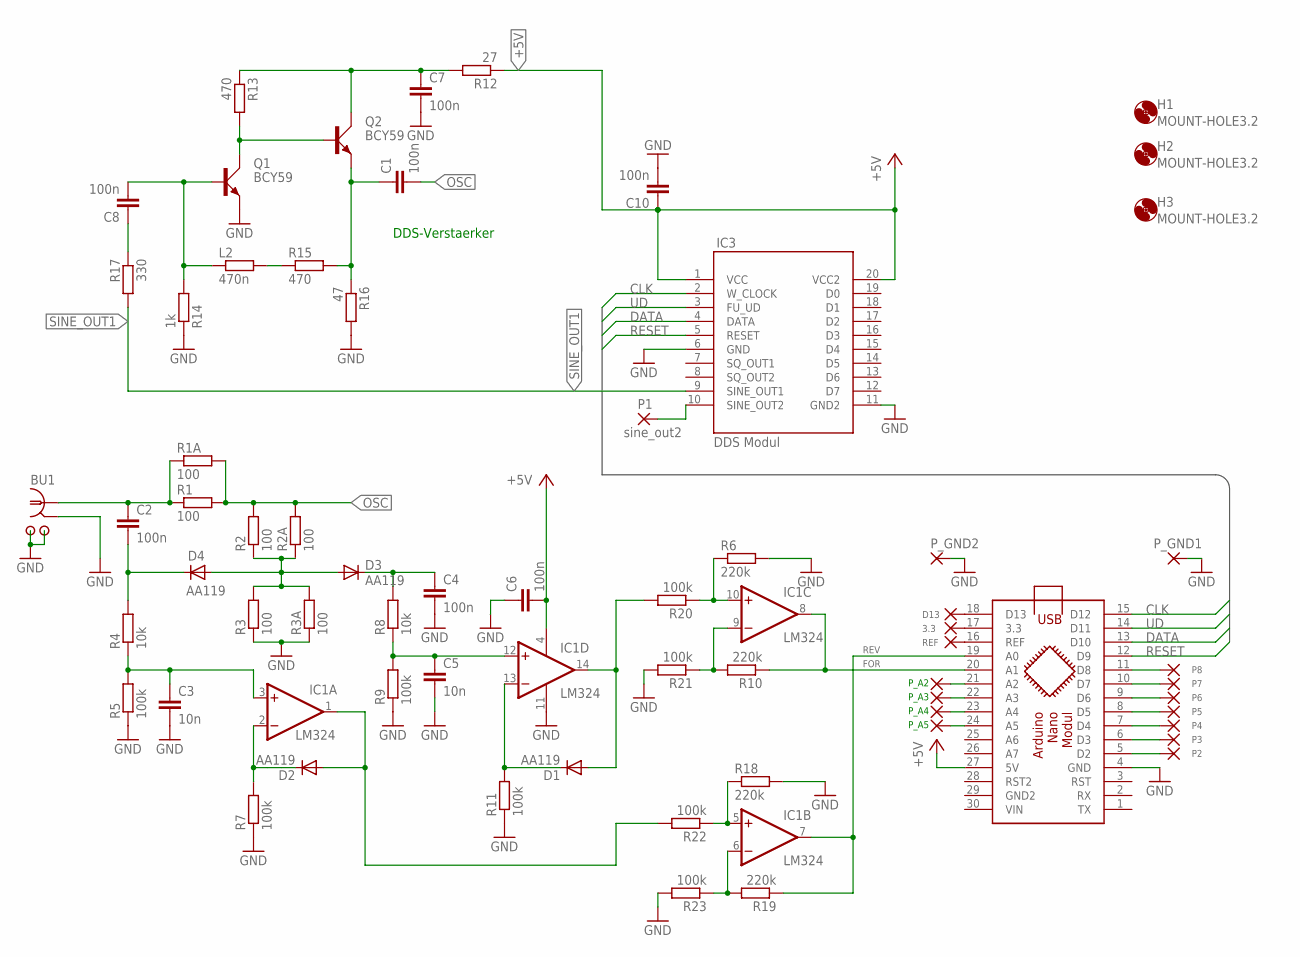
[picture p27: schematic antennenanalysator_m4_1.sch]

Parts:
3.3: 1,6/0,8
ARDIUNO_NANO: ARDUINO_NANO
BU1: BNC_1BNC_L; BNC
C1, C2, C4, C6, C7, C8, C10: 100n; C025-025X050
C3, C5: 10n; C025-025X050
D1, D2, D3, D4: AA119; DO07
D13: 1,6/0,8
H1, H2, H3: MOUNT-HOLE3.2; 3,2
IC1: LM324; DIL14
IC3: DDS Modul; MODULE
L2: 470n; 0207/10
P1: sine_out2; 1,6/0,8
P2, P3, P4, P5, P6, P7, P8: 1,6/0,8
P_A2: 1,6/0,8
P_A3, P_A4, P_A5: 1,6/0,8
P_GND1, P_GND2: 1,6/0,8
Q1, Q2: BCY59; TO18A
R1, R1A, R2, R2A, R3, R3A: 100; 0207/10
R4, R8: 10k; 0207/10
R5, R7, R9, R11, R20, R21, R22, R23: 100k; 0207/10
R6, R10, R18, R19: 220k; 0207/10
R12: 27; 0207/10
R13, R15: 470; 0207/10
R14: 1k; 0207/10
R16: 47; 0207/10
R17: 330; 0207/10
REF: 1,6/0,8

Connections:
+5V: ARDIUNO_NANO.27 (5V), C6.2, C10.1, IC1.4 (V+), IC3.1 (VCC), IC3.20 (VCC2), R12.1
ANT: BU1.SIGNAL (SEELE), C2.1, R1.1, R1A.1
CLK: ARDIUNO_NANO.15 (D12), IC3.2 (W_CLOCK)
D3_K: C4.1, D3.C, R8.2
D4_K: C2.2, D4.C, R4.2
DATA: ARDIUNO_NANO.13 (D10), IC3.4 (DATA)
FOR: ARDIUNO_NANO.20 (A1), IC1.8 (OUT), R10.1
GND: ARDIUNO_NANO.4 (GND), BU1.GND, BU1.M1, BU1.M2, C3.2, C4.2, C5.2, C6.1, C7.2, C10.2, IC1.11 (V-), IC3.6 (GND), IC3.11 (GND2), P_GND1.1, P_GND2.1, Q1.E, R3.1, R3A.1, R5.1, R6.2, R7.1, R9.1, R11.1, R14.1, R16.2, R18.2, R21.2, R23.2
unnamed: C3.1, IC1.3 (+IN), R4.1, R5.2
unnamed: ARDIUNO_NANO.16 (REF), REF.1
unnamed: D3.A, D4.A, R2.1, R2A.1, R3.2, R3A.2
unnamed: D2.C, IC1.2 (-IN), R7.2
unnamed: 3.3.1, ARDIUNO_NANO.17 (3.3)
unnamed: ARDIUNO_NANO.18 (D13), D13.1
unnamed: C5.1, IC1.12 (+IN), R8.1, R9.2
unnamed: D1.C, IC1.13 (-IN), R11.2
unnamed: C7.1, Q2.C, R12.2, R13.1
unnamed: C8.1, R17.1
unnamed: L2.2, R15.1
unnamed: Q1.C, Q2.B, R13.2
unnamed: C1.1, Q2.E, R15.2, R16.1
unnamed: C8.2, L2.1, Q1.B, R14.2
unnamed: IC3.10 (SINE_OUT2), P1.1
unnamed: ARDIUNO_NANO.11 (D8), P8.1
unnamed: ARDIUNO_NANO.10 (D7), P7.1
unnamed: ARDIUNO_NANO.9 (D6), P6.1
unnamed: ARDIUNO_NANO.8 (D5), P5.1
unnamed: ARDIUNO_NANO.7 (D4), P4.1
unnamed: ARDIUNO_NANO.6 (D3), P3.1
unnamed: ARDIUNO_NANO.5 (D2), P2.1
unnamed: ARDIUNO_NANO.21 (A2), P_A2.1
unnamed: D1.A, IC1.14 (OUT), R20.2
unnamed: IC1.9 (-IN), R10.2, R21.1
unnamed: D2.A, IC1.1 (OUT), R22.2
unnamed: IC1.6 (-IN), R19.2, R23.1
unnamed: ARDIUNO_NANO.22 (A3), P_A3.1
unnamed: ARDIUNO_NANO.23 (A4), P_A4.1
unnamed: IC1.5 (+IN), R18.1, R22.1
unnamed: IC1.10 (+IN), R6.1, R20.1
unnamed: ARDIUNO_NANO.24 (A5), P_A5.1
OSC: C1.2, R1.2, R1A.2, R2.2, R2A.2
RESET: ARDIUNO_NANO.12 (D9), IC3.5 (RESET)
REV: ARDIUNO_NANO.19 (A0), IC1.7 (OUT), R19.1
SINE_OUT1: IC3.9 (SINE_OUT1), R17.2
UD: ARDIUNO_NANO.14 (D11), IC3.3 (FU_UD)

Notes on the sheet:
DDS-Verstaerker

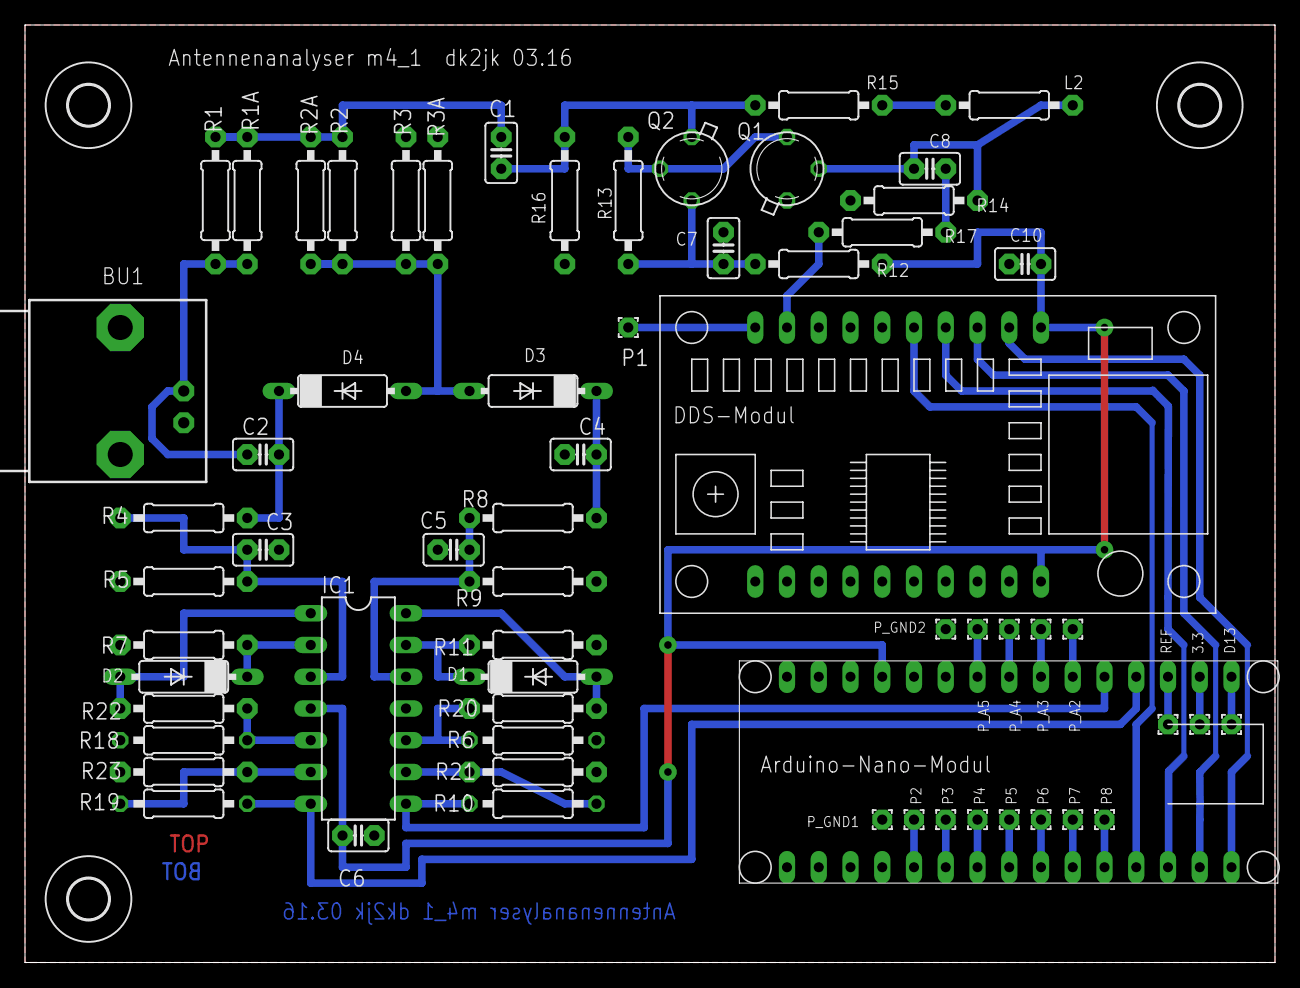
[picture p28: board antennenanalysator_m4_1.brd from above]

Board: 2 copper layers, 100.0 x 75.0 mm, 66 parts (0 on the bottom side), 45 nets.

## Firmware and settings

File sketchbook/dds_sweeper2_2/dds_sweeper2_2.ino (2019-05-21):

#include <EEPROM.h>
#include "cw.h"

/***
 * update 12 02 2016 Version "dds_sweeper2_2"
 * - Korrektur Tunefunktion 't' und Funktion 'c' ( On/off DDS)
 * 
   update 16 01 2016 Version "dds_sweeper2_1"
   - bakengeschwindigkeit von 18 auf 12 wpm erniedrigt.
   - dds_off() bei ende des sweep
   - dds_off() bei beliebiger taste
   - befehl 't' = "tune": sendet traeger mit der startfrequenz ( 'a' oder 'c' )
*/
/***************************************************************************\
    Name    : DDS_Sweeper2
    Author  : Beric Dunn (K6BEZ)
    Notice  : Copyright (c) 2013  CC-BY-SA
            : Creative Commons Attribution-ShareAlike 3.0 Unported License
    Date    : 9/26/2013  10/2015 (hs)
    Version : n
    Notes   : Written using for the Arduino
            :   Pins:
            :    A0 - Reverse Detector Analog in
            :    A1 - Forward Detector Analog in
            : Modified by Norbert Redeker (DG7EAO) 07/2014
            : Modified by Heribert Schulte dk2jk 09/2014 //(hs)
            : mit verstaerker hinter dds, (Hardware m4) okt 2015
            : 17.10.15 bake
  \***************************************************************************/

// Define Pins used to control AD9850 DDS

// board ..
const int SCLK  = 12;
const int FQ_UD = 11;
const int SDAT  = 10;
const int RESET = 9;

double Fstart_MHz = 1.0;  // Start Frequency for sweep
double Fstop_MHz = 30.000;  // Stop Frequency for sweep
double current_freq_MHz; // Temp variable used during sweep
long serial_input_number; // Used to build number from serial stream
int num_steps = 100; // Number of steps to use in the sweep
//char incoming_char; // Character read from serial stream
double offset_forward;
double offset_reverse;
bool interpreter_aktiv = false;
bool tune_aktiv = false;

struct s_eeprom {
  char text[40]; // das ist der text fuer die bake
};
s_eeprom eeprom;

const char  SoftwareVersion[] = "Software Version: " __FILE__; //"Vers.:dds_sweeper1_13dez2014.ino";
const char     SoftwareDate[] = "Build Date      : " __DATE__; //"Vers.:dds_sweeper1_13dez2014.ino";
Cw bake(12);  // 2_1 speed von 18 auf 12 erniedrigt

// the setup routine runs once when you press reset:
void setup() {
  // Configiure DDS control pins for digital output
  pinMode(FQ_UD, OUTPUT);
  pinMode(SCLK, OUTPUT);
  pinMode(SDAT, OUTPUT);
  pinMode(RESET, OUTPUT);

  // Configure LED pin for digital output
  pinMode(13, OUTPUT);


  // Set up analog inputs on A0 and A1, internal reference voltage
  pinMode(A0, INPUT);
  pinMode(A1, INPUT);
  analogReference(INTERNAL); // ref voltage = 1,1 volt


  // initialize serial communication at 57600 baud
  Serial.begin(57600);

  // Reset the DDS
  digitalWrite(RESET, HIGH);
  digitalWrite(RESET, LOW);

  //Initialise the incoming serial number to zero
  serial_input_number = 0;

  EEPROM.get(0, eeprom);
  calc_offset();
  version();
  Serial.flush();

}

void interpreter(char rxd)
{
  switch (rxd) {
    case '0':
    case '1':
    case '2':
    case '3':
    case '4':
    case '5':
    case '6':
    case '7':
    case '8':
    case '9':  // eingabezahl ansammeln
      serial_input_number = serial_input_number * 10 + (rxd - '0');
      break;
    case 'A':  // 7000000A
    case 'a':
      //Turn frequency into FStart
      Fstart_MHz = ((double)serial_input_number) / 1000000;
      serial_input_number = 0;
      break;
    case 'B': // 10000000B
    case 'b':
      //Turn frequency into FStop
      Fstop_MHz = ((double)serial_input_number) / 1000000;
      serial_input_number = 0;
      break;
    case 'C':  // 7032000C
    case 'c':
      //Turn frequency into FStart and set DDS output to single frequency
      Fstart_MHz = ((double)serial_input_number) / 1000000;
      //SetDDSFreq(Fstart_MHz);
      SetDDSFreq(Fstart_MHz * 1000000);
      delay(100);
      SetDDSFreq(Fstart_MHz * 1000000);
      serial_input_number = 0;
      break;
    case 'N': // 100N
    case 'n':
      // Set number of steps in the sweep
      num_steps = serial_input_number;
      serial_input_number = 0;
      break;
    case 'S':
    case 's':
      Perform_sweep();
      break;
    case '!':
      inputText();
      break;
    case '#':
      runBake();
      break;
    case 't':
      if ( tune_aktiv)
      { dds_off();
        Serial.println("tune off");
        tune_aktiv = false;
      }
      else
      { tune();
        Serial.println("tune on");
        tune_aktiv = true;
      }
      break;
    case '?':
      sweep_info();
      Serial.println();
      break;
    case 'h':
    case 'H':
      help();
      break;
    case 'v':
    case 'V':
      version();
      break;
  }
}
void sweep_info() {
  Serial.println("--- Sweep info ---");
  Serial.print("Start Freq:\t");
  Serial.println(Fstart_MHz * 1000000);
  Serial.print("Stop Freq:\t");
  Serial.println(Fstop_MHz * 1000000);
  Serial.print("Num Steps:\t");
  Serial.println(num_steps);
  Serial.println();
}
void version()
{ Serial.println(SoftwareVersion);
  Serial.println(SoftwareDate);
  Serial.println();
}
void help()
{ Serial.println("---- commands---");
  Serial.println("letter\tdescription\t\texample\t\tresult");
  Serial.println("'a'\tset start frequency\t6000000a\t6.000 Mhz");
  Serial.println("'b'\tset end frequency\t8000000b\t8.000 Mhz");
  Serial.println("'c'\tset constant frequency\t7032000c\t7.032 Mhz");
  Serial.println("'n'\tset numer of steps\t100n\t\t100 steps");
  Serial.println("'s'\tperform sweep from frequency a to b with n steps");
  Serial.println("'?'\tsweep info");
  Serial.println("'h'\thelp");
  Serial.println("'v'\tsoftware version");
  Serial.println("---- commands may be lower or upper case ----");
  Serial.println("Gimmick:");
  Serial.println("'t'\t\"tune\" on/off ; send carrier with start frequency ( command 'a' or 'c' )");
  Serial.println("'!'\tstore following text in EEPROM for beacon tx, end with <enter>");
  Serial.println("'#'\tsend beacon tx text again and again ( break with '#' )");
  Serial.println(" \tBeacon frequency is start frequency ( command 'a' or 'c' )");
  Serial.print("actual beacon text: \"");
  EEPROM.get(0, eeprom);
  Serial.print(eeprom.text);
  Serial.println("\"");
  Serial.print("Info offset forward: ");
  Serial.print(offset_forward, 0);
  Serial.print("; reverse: ");
  Serial.println(offset_reverse, 0);
  Serial.println();
}


// the loop routine runs over and over again forever:
void loop() {
  //Check for character
  if (Serial.available() > 0)
  { interpreter( Serial.read() );
    Serial.flush();
  }
}

void calc_offset()
{ int i;
  int n = 16;
  SetDDSFreq(0.0); //frequenz auf null einstellen
  delay(100);
  SetDDSFreq(0.0); //frequenz auf null einstellen
  delay(100);
  offset_reverse = 0;
  offset_forward = 0;
  for (i = 0; i < n; i++)
  { offset_reverse += (double)analogRead(A0);
    offset_forward += (double)analogRead(A1);
    delay(100);
  }
  offset_reverse =   offset_reverse / n;
  offset_forward  =  offset_forward / n;
}
void Perform_sweep() {
  double FWD = 0;
  double REV = 0;
  double VSWR;
  double Fstep_MHz = (Fstop_MHz - Fstart_MHz) / num_steps;

  // Start loop
  for (int i = 0; i <= num_steps; i++) {
    // Calculate current frequency
    current_freq_MHz = Fstart_MHz + i * Fstep_MHz;
    // Set DDS to current frequency
    SetDDSFreq(current_freq_MHz * 1000000);
    // Wait a little for settling
    delay(100);
    // Read the forawrd and reverse voltages
    REV = (double)analogRead(A0) - offset_reverse;
    FWD = (double)analogRead(A1) - offset_forward;
    if (REV >= FWD)
    { REV = FWD - 1;
    }
    if (REV < 1)
    { REV = 1;
    }
    VSWR = (FWD + REV) / (FWD - REV);

    if (VSWR >= 29.0)
    { VSWR = 28.999;
    }
    //Skalieren fuer Ausgabe
    VSWR = VSWR * 1000.0;

    // Send current line back to PC over serial bus
    Serial.print(current_freq_MHz * 1000000);
    Serial.print(", 0, ");
    Serial.print(VSWR, 5);
    Serial.print(", ");
    Serial.print(FWD, 0);
    Serial.print(", ");
    Serial.println(REV, 0);
  }
  // Send "End" to PC to indicate end of sweep
  dds_off();
  Serial.println("End");
  Serial.flush();
}

void SetDDSFreq(double Freq_Hz)
{ // Calculate the DDS word - from AD9850 Datasheet
  int32_t f = Freq_Hz * 4294967295 / 125000000;
  // Send one byte at a time
  for (int b = 0; b < 4; b++, f >>= 8)
  { send_byte(f & 0xFF);
  }
  // 5th byte needs to be zeros
  send_byte(0);
  // Strobe the Update pin to tell DDS to use values
  digitalWrite(FQ_UD, HIGH);
  digitalWrite(FQ_UD, LOW);
}

void send_byte(byte data_to_send) {
  // Bit bang the byte over the SPI bus
  for (int i = 0; i < 8; i++, data_to_send >>= 1)
  { // Set Data bit on output pin
    digitalWrite(SDAT, data_to_send & 0x01);
    // Strobe the clock pin
    digitalWrite(SCLK, HIGH);
    digitalWrite(SCLK, LOW);
  }
}

void inputText()
{ int i;
  eeprom.text[0] = ' ';
  for (i = 1; i < sizeof(eeprom.text); i++)
  { do
    {} while (Serial.available() == 0);
    char c = Serial.read();
    if ( (c == 0x0d ) || (c == 0x0a))
    { break;
    }
    else
    { eeprom.text[i] = c;
    }
  }
  eeprom.text[i] = 0;
  EEPROM.put(0, eeprom);
}

void runBake() {
  bool ende = false;
  Serial.print("bake laeuft! stop '#' ");
  EEPROM.get(0, eeprom);
  bake.setText(eeprom.text);
  do
  { bake.start();
    while ( bake.busy() )
    { if (Serial.available() > 0)
      { char c;
        c = Serial.read();
        if (c == '#')
        { bake.stop();
          ende = true;
          break;
        }
      }
      bake.run();
      if (bake.key)
      { SetDDSFreq(Fstart_MHz * 1000000);
      }
      else
      { SetDDSFreq(0.0);
      }
    }
  } while ( !ende);
  dds_off();
  Serial.println(".. ende");
}

void tune()
{ SetDDSFreq(Fstart_MHz * 1000000);
}

void dds_off()
{ SetDDSFreq(0L); // Null hertz = AUS
}
